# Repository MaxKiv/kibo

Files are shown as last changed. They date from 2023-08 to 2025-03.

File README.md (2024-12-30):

# The KiBo splitboard

An awesome custom split keyboard, at least I think so 😉. Made by Max Kivits and
Timon Borg, the KiBo!

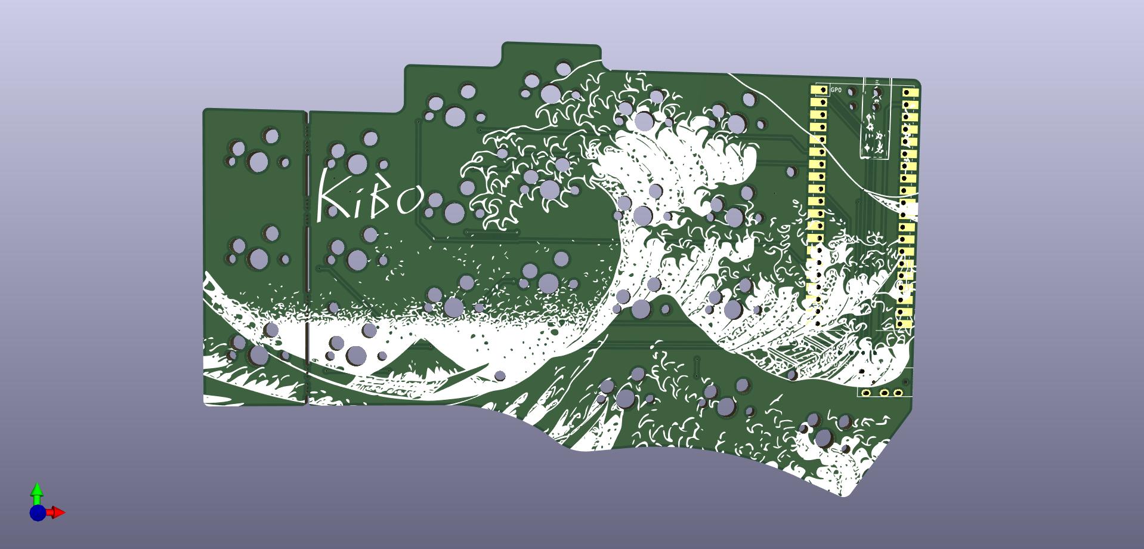
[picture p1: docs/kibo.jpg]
kibo


This keyboard is loosely based on the [Piantor] and [Cantor] keyboards. It's a
42-key diodeless non-flippable cherry-mx hotswapable mechanical split keyboard
with aggressive column staggering. It's powered by 2 RP2040, completely overkill!
I redesigned the PCB to use cherry-mx style hotswap switches and adjusted the
margins so it fits my hands better.
The pcb features an artsy silklayer, because why not?

The casing is designed by Timon Borg, a god amongst fusion360 users!

KiBo uses the amazing [qmk] firmware to become a keyboard.



## Features

* RP2040 MCU - A low-cost, easy-to-source, powerful microcontroller with dual Arm Cortex-M0+ @ 133MHz, 264kB on-chip SRAM and 2MB (up to 16MB, depending on the breakout board) off-chip external flash memory. You can enable a lot of features and layers. Never worry about the firmware size limit.
* Cantor layout - Ergonomic strong column staggering for short pinkies.
* Non-flippable PCBs - Fewer ways to make mistakes when you install the controller breakout boards. Great for first time keyboard builders.
* Diodeless - A more robust build with fewer things to solder or break.
* Hybrid hotswap and soldered-in low profile choc switches - Experiment with different key switches with the hotswap sockets, or solder the key switches for a more stable build.
* Breakable pinky column - Easily convert the PCB from a 42-key to 36-key layout. You can snap off the pinky column without specialized tools.

## Bill of Materials (BOM)

Quantity | Item | Notes
--- | --- | ---
1 | KiBo PCB (Left)
1 | KiBo PCB (Right)
2 | RP2040 breakout boards (such as Raspberry Pi Pico or WeAct RP2040)
42 (or 36) | cherry-mx style switches of your favorite flavor
42 (or 36) | cherry-mx style keycaps of your favorite variety
2 | TRRS jack (PJ-320A)
1 | 3.5mm TRRS cable | TRS cable cannot be used
42 (or 36) | cherry-mx style hotswap sockets | Optional, you can solder the switches directly if you do not use hotswap sockets
4 | Pin headers (20p) or sockets  | Only required for boards without castellated holes
2 | 10kΩ 1206 (3216M) SMD resistor | Only required if you do not want to use SPLIT_USB DETECT, and for boards without a built in VBUS_SENSE circuit
2 | 5.6kΩ 1206 (3216M) SMD resistor | Only required if you do not want to use SPLIT_USB DETECT, and for boards without a built in VBUS_SENSE circuit
1 | KiBo Case (Left) | 3D print your own
1 | KiBo Case (Right)| 3D print your own

* Note: Raspberry Pi Pico comes with castellated holes and a built in VBUS_SENSE circuit

[Piantor]: https://github.com/beekeeb/piantor
[Cantor]: https://github.com/diepala/cantor
[qmk]: https://github.com/qmk/qmk_firmware

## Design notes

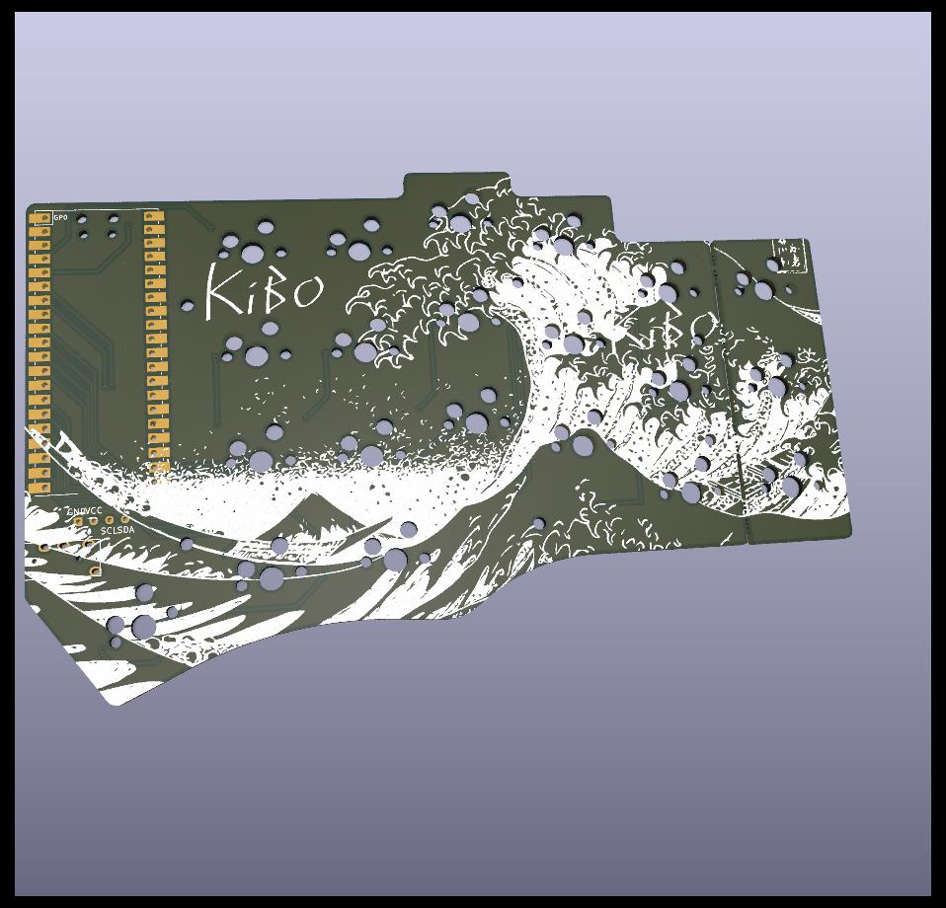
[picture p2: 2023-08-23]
docs/left.jpg

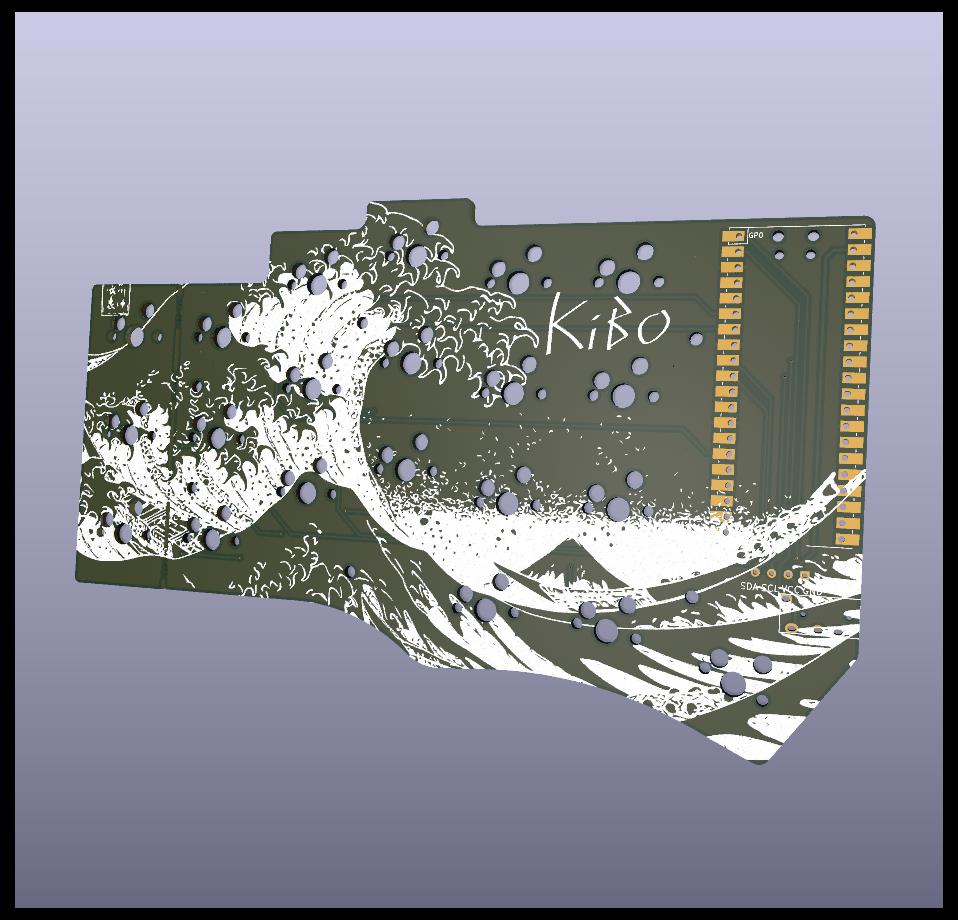
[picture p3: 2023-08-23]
docs/right.jpg

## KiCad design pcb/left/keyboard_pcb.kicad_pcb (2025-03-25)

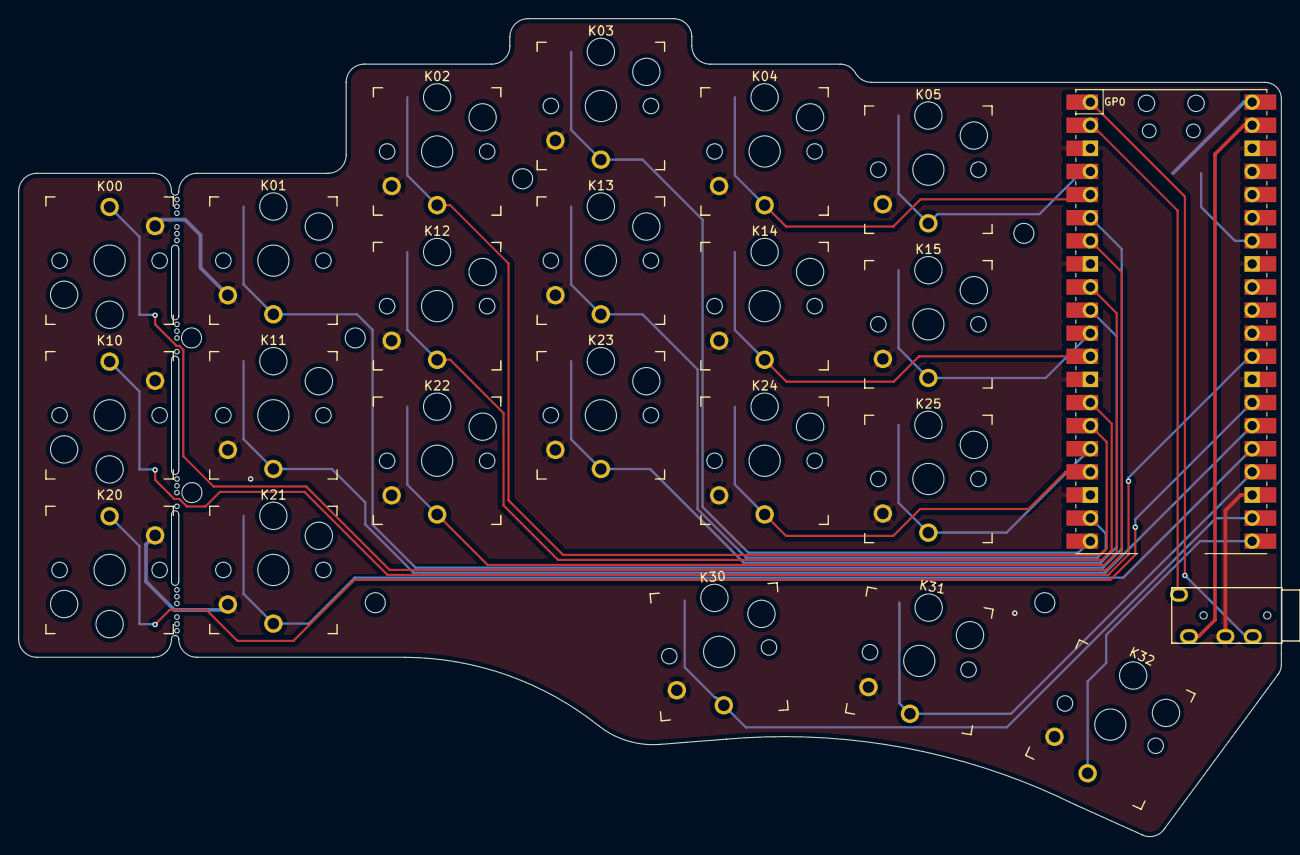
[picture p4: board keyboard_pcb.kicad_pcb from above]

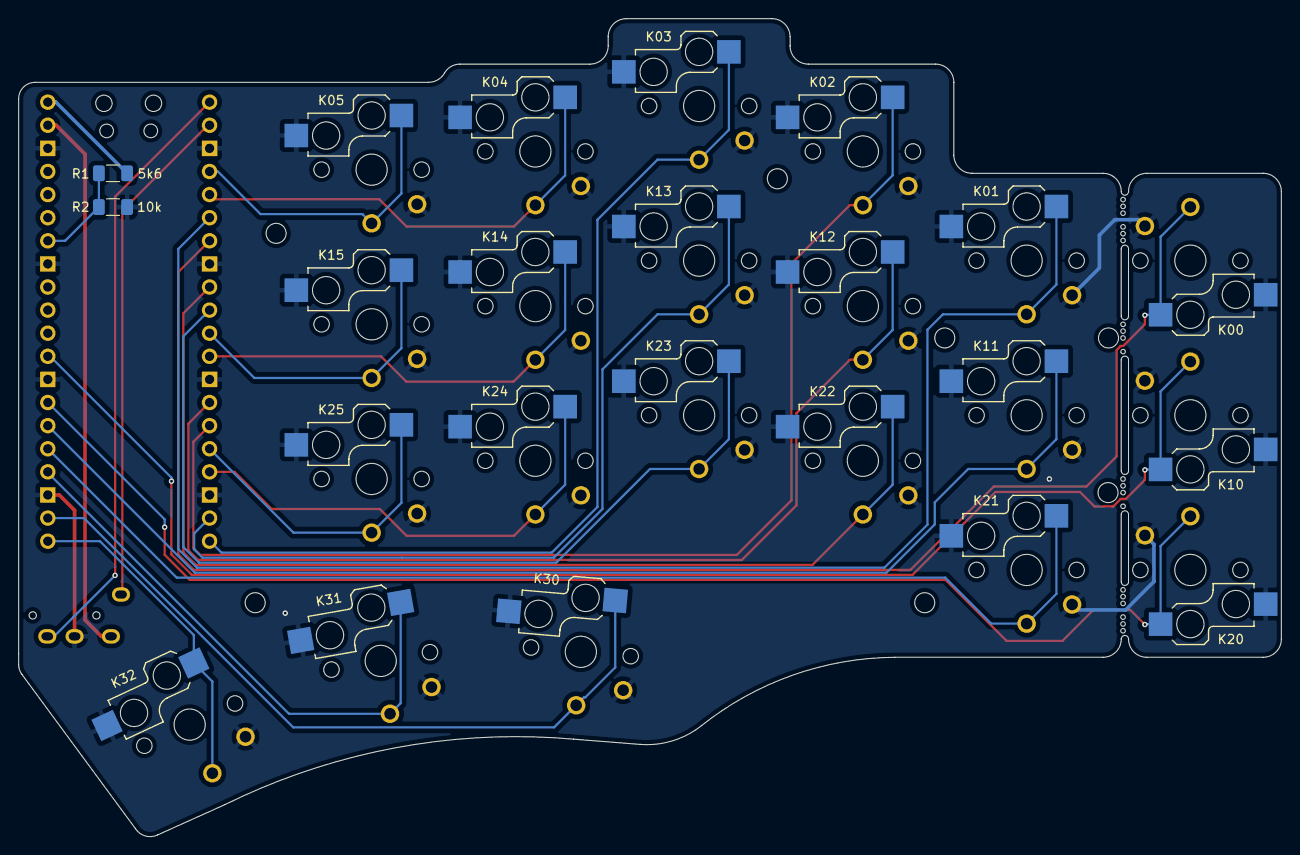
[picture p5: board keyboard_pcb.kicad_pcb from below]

Board: 2 copper layers, 138.8 x 89.9 mm, 36 parts (2 on the bottom side), 27 nets.

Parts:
H1, H1#2, H2, H3, H4, H4#2, H4#3: MountingHole; MountingHole_2.2mm_M2-8mm
J1: TRRS; TRRS-PJ-320A
K00, K01, K02, K03, K04, K05, K10, K11, K12, K13, K14, K15, K20, K21, K22, K23, K24, K25, K30, K31, K32: KEYSW; Kailh_socket_PG1350_optional
MB1, MB2: MountingHole; mousebites_2
MB3, MB4: MountingHole; mousebites_3
R1: 5k6; R_1206_3216Metric_Pad1.30x1.75mm_HandSolder
R2: 10k; R_1206_3216Metric_Pad1.30x1.75mm_HandSolder
U2: Pico; RPi_Pico_SMD_TH

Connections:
/k00: K00.1, U2.7 (GPIO5)
/k01: K01.1, U2.6 (GPIO4)
/k02: K02.1, U2.15 (GPIO11)
/k03: K03.1, U2.20 (GPIO15)
/k04: K04.1, U2.5 (GPIO3)
/k05: K05.1, U2.4 (GPIO2)
/k10: K10.1, U2.29 (GPIO22)
/k11: K11.1, U2.26 (GPIO20)
/k12: K12.1, U2.14 (GPIO10)
/k13: K13.1, U2.19 (GPIO14)
/k14: K14.1, U2.12 (GPIO9)
/k15: K15.1, U2.11 (GPIO8)
/k20: K20.1, U2.27 (GPIO21)
/k21: K21.1, U2.25 (GPIO19)
/k22: K22.1, U2.9 (GPIO6)
/k23: K23.1, U2.10 (GPIO7)
/k24: K24.1, U2.17 (GPIO13)
/k25: K25.1, U2.16 (GPIO12)
/k30: K30.1, U2.22 (GPIO17)
/k31: K31.1, U2.24 (GPIO18)
/k32: K32.1, U2.21 (GPIO16)
GND: J1.3 (RING1), K00.2, K01.2, K02.2, K03.2, K04.2, K05.2, K10.2, K11.2, K12.2, K13.2, K14.2, K15.2, K20.2, K21.2, K22.2, K23.2, K24.2, K25.2, K30.2, K31.2, K32.2, R2.2, U2.3 (GND), U2.8 (GND), U2.13 (GND), U2.18 (GND), U2.23 (GND), U2.28 (GND), U2.33 (AGND), U2.38 (GND)
VBUS: R1.1, U2.40 (VBUS)
VCC: J1.2 (TIP), U2.39 (VSYS)
rx: J1.1 (SLEEVE), U2.2 (GPIO1)
tx: J1.4 (RING2), U2.1 (GPIO0)
vbus_sense: R1.2, R2.1, U2.34 (GPIO28_ADC2)

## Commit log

2023-08-23 feat: new keyboard!
    [max.kicad_sch]
2023-08-23 feat: right keyboard, silkscreen
    [keyboard_pcb.kicad_pcb, max.kicad_sch]
2023-09-23 nice commit msg
    [max-B_Cu.gbl, max-B_Mask.gbs, max-B_Paste.gbp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]
2025-03-25 feat(nix): add nix devshell
    [keyboard_pcb.kicad_pcb]

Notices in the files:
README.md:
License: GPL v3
